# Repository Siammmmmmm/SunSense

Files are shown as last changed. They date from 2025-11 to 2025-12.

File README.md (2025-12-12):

# SunSense
>Automated Smart Blinds System

A real-time embedded system that automatically opens or closes window blinds based on ambient light level and user gestures. The system uses light sensors to detect brightness conditions and Time-of-Flight sensors with TinyML to recognize simple hand gestures for manual override.

# Setup and Deployment

To build this project, you'll need an Arduino Nano 33 BLE Sense Rev2, a Nema 17 stepper motor with DRV8825 driver, one TSL2561 light sensor, four VL53L1X Time of Flight sensors, and a 12V 3A power supply. Install the required Arduino libraries (Adafruit TSL2561, Adafruit VL53L1X, and Adafruit Unified Sensor) through the Arduino IDE Library Manager. Wire the TSL2561 to the Arduino's I2C pins (SDA/SCL) and 3.3V power. Connect all four VL53L1X sensors to the same I2C bus with their XSHUT pins connected to digital pins 5, 6, 7, and 8 to assign unique addresses during initialization. Wire the DRV8825 motor driver to the 12V power supply and connect its control pins: STEP to pin 2, DIR to pin 3, ENABLE to pin 4, and SLP (sleep) to pin 9. Connect the stepper motor to the driver's output pins. Clone the code and upload Main/SunSense.ino to your Arduino. The system uses three concurrent threads - one for light sensing, one for ToF data collection, and one for TinyML gesture recognition. Attach the motor to your blind rod using the 3D printed coupling that allows it to rotate the rod.

# How to Use and Interact

Once powered on, the system runs three parallel tasks automatically. The light sensing thread checks the ambient light level every 10 minutes and rotates the motor 3 full rotations to open or close the blinds when the light crosses the threshold of 6 lux. The ToF thread continuously samples all four distance sensors at approximately 20 Hz, and the Ai thread collects one second of ToF data and runs a TinyML gesture recognition model on it. When a gesture is detected with at least 95% confidence, the system overrides the automatic mode and toggles the blinds (with a 2-second cooldown between gestures to prevent accidental triggers). You can manually control the blinds by waving your hand toward the four ToF sensors positioned in front of the device. The system alternates between opening and closing with each detected gesture. All activity is logged to the Serial Monitor at 115200 baud if you want to debug or monitor the system's behavior.

>[Demo Link](https://buffalo.box.com/s/utygu3p5m2xhpubo7brv89h74q1jszoa)

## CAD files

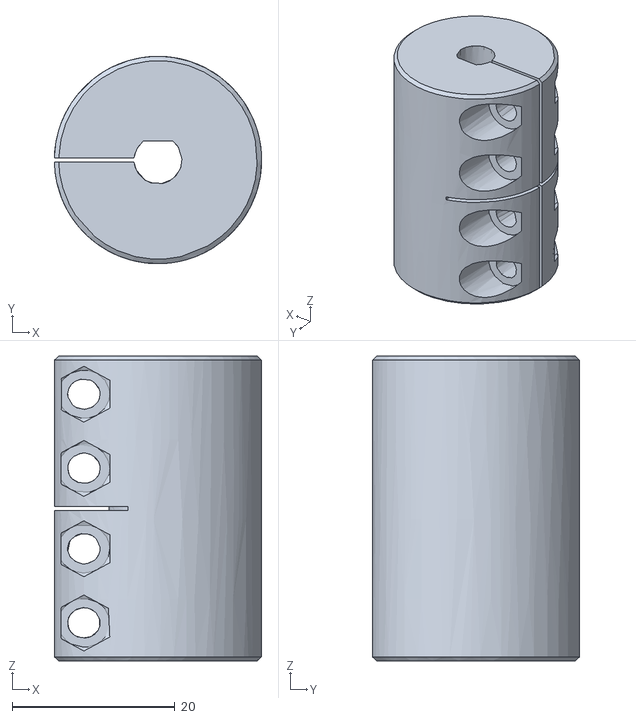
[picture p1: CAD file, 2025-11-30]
3DPrint/Coupler.stl
25.5 x 25.5 x 37.5

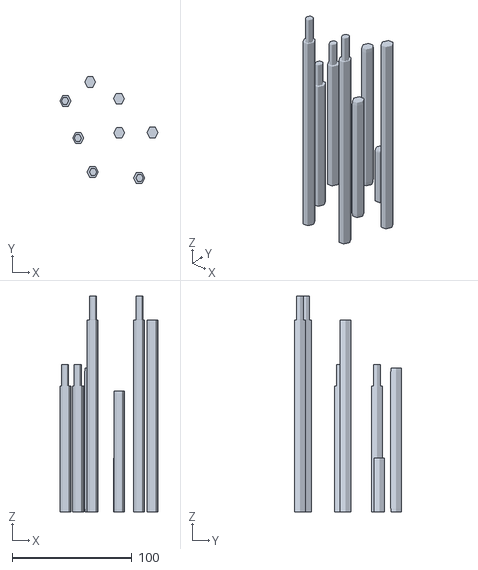
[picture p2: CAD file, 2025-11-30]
3DPrint/Rods.stl
81.8 x 89.2 x 180.0

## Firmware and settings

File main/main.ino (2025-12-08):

#include <Arduino.h>
#include <SunSense_inferencing.h>
#include "mbed.h"
#include <rtos.h>
#include <Wire.h>
#include <Adafruit_Sensor.h>
#include <Adafruit_TSL2561_U.h>
#include <VL53L1X.h>

using namespace mbed;
using namespace rtos;
using namespace std::chrono_literals;

// --- Pin Definitions ---
#define STEP_PIN 2
#define DIR_PIN 3
#define ENABLE_PIN 4  // DRV8825: LOW=enable, HIGH=disable
#define SLP_PIN 9     // LOW=disable, HIGH=enable

// --- tof ---
const uint8_t sensorCount = 4;

// Shared latest TOF readings (updated by tofThread, read by aiThread)
volatile uint16_t tofValues[sensorCount] = { 0, 0, 0, 0 };

// XSHUT pins
const uint8_t xshutPins[sensorCount] = { 5, 6, 7, 8 };

// --- motor out ---
DigitalOut stepPin(digitalPinToPinName(STEP_PIN));
DigitalOut dirPin(digitalPinToPinName(DIR_PIN));
DigitalOut enPin(digitalPinToPinName(ENABLE_PIN));
DigitalOut slpPin(digitalPinToPinName(SLP_PIN));

// --- Sensor Objects ---
Adafruit_TSL2561_Unified tsl = Adafruit_TSL2561_Unified(TSL2561_ADDR_FLOAT, 12345);
VL53L1X tof[sensorCount];

// --- Parameters ---
const int lightThreshold = 6;  // lux value to trigger movement (adjust as needed)
int bright = 1;
volatile bool motorActive = false;
// bool luxPause = false;

// --- RTOS objects ---
Mutex printMutex;  // guard Serial printing
Mutex motorMutex;  // guard motor operations
Mutex tofMutex;    // guard tof readings

Thread luxThread;
Thread tofThread;
Thread aiThread;

void pulse(int microsec) {
  stepPin = 1;
  wait_us(microsec);
  stepPin = 0;
  wait_us(microsec);
}

// motor moves
/*ex:
2 full rotations  = 2072 steps
full rotation     = 1036 steps
half              = 518 steps
quarter           = 259 steps
*/
void moveSteps(int steps, bool dir, int freqHz) {
  motorMutex.lock();
  motorActive = true;

  // Wake motor driver
  slpPin = 1;  // awake
  dirPin = dir ? 1 : 0;
  enPin = 0;  // enable driver

  {
    printMutex.lock();
    Serial.print("MOTOR : ");
    Serial.println(dir ? "Forward" : "Backward");
    printMutex.unlock();
  }

  int microsec = (int)(1e6 / (freqHz * 2.0f));
  for (long i = 0; i < steps; i++) pulse(microsec);

  enPin = 1;   // disable outputs (no idle heat)
  slpPin = 0;  // sleep

  motorActive = false;
  motorMutex.unlock();
}

void tofInit() {
  for (int i = 0; i < sensorCount; i++) {
    pinMode(xshutPins[i], OUTPUT);
    digitalWrite(xshutPins[i], LOW);
  }
  ThisThread::sleep_for(10ms);

  for (int i = 0; i < sensorCount; i++) {
    pinMode(xshutPins[i], INPUT);  //toggles xshut pins to later set proper address to indentify
    ThisThread::sleep_for(10ms);

    if (!tof[i].init()) {
      printMutex.lock();
      Serial.print("Failed to detect and initialize sensor ");
      Serial.println(i);
      printMutex.unlock();
      continue;
    }

    tof[i].setTimeout(50);
    tof[i].setDistanceMode(VL53L1X::Long);
    tof[i].setMeasurementTimingBudget(20000);  // 20ms == 20hz
    tof[i].setAddress(0x2A + i);
    tof[i].startContinuous(50);  // 1/50ms between readings == 20hz
  }
}

void luxInit() {
  if (!tsl.begin()) {
    printMutex.lock();
    Serial.println("SYSTEM: No TSL2561 found!");
    printMutex.unlock();
    return;
  }
  printMutex.lock();
  Serial.println("SYSTEM: TSL2561 initialized!");
  printMutex.unlock();

  tsl.enableAutoRange(true);
  tsl.setIntegrationTime(TSL2561_INTEGRATIONTIME_13MS);
}

void luxTask() {
  const int reps = 3;
  while (true) {
    sensors_event_t event;
    tsl.getEvent(&event);
    // if (luxPause) {
    //   ThisThread::sleep_for(10000ms);
    //   luxPause = false;
    //   continue;
    // }

    if (event.light && !isnan(event.light)) {
      printMutex.lock();
      Serial.print("LIGHT : ");
      Serial.print(event.light);
      Serial.println(" lux!");
      printMutex.unlock();

      if (event.light < lightThreshold && bright == 0) {
        printMutex.lock();
        Serial.println("LIGHT : Too dark -> rotating clockwise");
        printMutex.unlock();

        moveSteps(1036 * reps, true, 100);  // 1036 steps(1 full rotation * num of rotations), direction, motor hz
        bright = 1;                         // confirmation for blinds
      } else if (event.light > lightThreshold && bright == 1) {
        printMutex.lock();
        Serial.println("LIGHT : bright enough -> rotating counterclockwise");
        printMutex.unlock();

        moveSteps(1036 * reps, false, 100);  //1036 steps(1 full rotation * num of rotations), direction, motor hz
        bright = 0;
      }
    } else {
      printMutex.lock();
      Serial.println("LIGHT : No light data");
      printMutex.unlock();
    }

    ThisThread::sleep_for(600000ms);
  }
}

void tofTask() {
  const uint32_t SAMPLE_INTERVAL_MS = 50;  // 20hz

  while (true) {
    if (motorActive) {
      ThisThread::sleep_for(5ms);
      continue;
    }

    uint16_t local[4] = { 0, 0, 0, 0 };

    for (uint8_t i = 0; i < sensorCount; i++) {
      int d = tof[i].read();
      bool timedOut = tof[i].timeoutOccurred();

      // if bad, reuse last known good reading
      if (timedOut || d <= 0) {
        d = tofValues[i];  // previous stable value
      }

      // clamp to sane physical range, synthetic tof values
      if (d < 100) d = 100;    // 10m min
      if (d > 4000) d = 4000;  // 4m max
      // -=-=-Sensor failsafe (misbehaves)-=-=-

      local[i] = (uint16_t)d;
    }

    tofMutex.lock();
    for (uint8_t i = 0; i < sensorCount; i++) {
      tofValues[i] = local[i];
    }
    tofMutex.unlock();

    printMutex.lock();
    Serial.print("TOF: ");
    for (uint8_t i = 0; i < sensorCount; i++) {
      Serial.print(local[i]);
      if (i < sensorCount - 1) Serial.print(", ");
    }
    Serial.println();
    printMutex.unlock();

    ThisThread::sleep_for(SAMPLE_INTERVAL_MS * 1ms);
  }
}

void aiTask() {
  ei_impulse_result_t result = { 0 };

  // expects EI_CLASSIFIER_DSP_INPUT_FRAME_SIZE floats
  static float inference_buffer[EI_CLASSIFIER_DSP_INPUT_FRAME_SIZE];  //Frame stuff given by EI: idk how this exactly works lol
  size_t buf_idx = 0;

  const uint32_t SAMPLE_INTERVAL_MS = 50;  // match TOF sampling at 50ms or 20hz
  const float GESTURE_THRESHOLD = 0.95f;   // 95% confidence needed
  uint32_t last_action_time = 0;
  const uint32_t COOLDOWN_MS = 2000;  // 2s cooldown between actions

  // extra gating
  const float MARGIN_THRESHOLD = 0.25f;  // gesture must beat next class by 0.25
  const int MOTION_THRESHOLD_MM = 50;    // min movement in mm to count as "motion"
  static int consecutive_gesture = 0;

  static bool first_sample = true;
  static uint16_t prev_tof[4] = { 0, 0, 0, 0 };
  static bool window_has_motion = false;

  // Find index of "gesture" label
  int gesture_idx = -1;
  for (size_t i = 0; i < EI_CLASSIFIER_LABEL_COUNT; i++) {
    if (strcmp(ei_classifier_inferencing_categories[i], "gesture") == 0) {
      gesture_idx = (int)i;
      break;
    }
  }
  if (gesture_idx < 0) {
    printMutex.lock();
    Serial.println("ERROR: 'gesture' label not found in model!");
    printMutex.unlock();
    return;
  }

  while (true) {
    // 1. Read latest TOF values under mutex
    uint16_t current_tof[4];
    tofMutex.lock();
    for (uint8_t i = 0; i < sensorCount; i++) {
      current_tof[i] = tofValues[i];
    }
    tofMutex.unlock();

    // --- motion detection vs previous sample ---
    if (first_sample) {
      for (int i = 0; i < 4; i++) prev_tof[i] = current_tof[i];
      first_sample = false;
    }

    int max_delta = 0;  //start to track changes in motion
    for (int i = 0; i < 4; i++) {
      int diff = (int)current_tof[i] - (int)prev_tof[i];
      if (diff < 0) diff = -diff;
      if (diff > max_delta) max_delta = diff; //checks if more than 50mm changed (redundant stuff to not over work the aithread)
    }
    for (int i = 0; i < 4; i++) prev_tof[i] = current_tof[i];

    if (max_delta > MOTION_THRESHOLD_MM) {
      window_has_motion = true;
    }

    // 2. Push one "frame" (4 sensors) into inference buffer
    inference_buffer[buf_idx++] = (float)current_tof[0];
    inference_buffer[buf_idx++] = (float)current_tof[1];
    inference_buffer[buf_idx++] = (float)current_tof[2];
    inference_buffer[buf_idx++] = (float)current_tof[3];

    // 3. When buffer full then 1 second of data collected
    if (buf_idx >= EI_CLASSIFIER_DSP_INPUT_FRAME_SIZE) {
      signal_t signal;

      int sf_res = numpy::signal_from_buffer(
        inference_buffer,
        EI_CLASSIFIER_DSP_INPUT_FRAME_SIZE,
        &signal);

      if (sf_res != 0) {
        printMutex.lock();
        Serial.print("signal_from_buffer failed: ");
        Serial.println(sf_res);
        printMutex.unlock();
      } else {
        EI_IMPULSE_ERROR rc = run_classifier(&signal, &result, false);

        if (rc != EI_IMPULSE_OK) {
          printMutex.lock();
          Serial.print("run_classifier failed: ");
          Serial.println((int)rc);
          printMutex.unlock();
        } else {

          if (!window_has_motion) {
            // no motion in this window so ignore any "gesture" output
            printMutex.lock();
            Serial.println("ML: window had no motion, forcing no_gesture");
            printMutex.unlock();
            consecutive_gesture = 0;
          } else {
            // 4. Find top-2 labels
            float gesture_prob = result.classification[gesture_idx].value;

            int best_idx = 0;
            float best_prob = result.classification[0].value;
            int second_idx = -1;
            float second_prob = 0.0f;

            // collects multiple frames into a window and chooses the best stable one and feeds into classifier
            for (size_t i = 1; i < EI_CLASSIFIER_LABEL_COUNT; i++) {
              float p = result.classification[i].value;
              if (p > best_prob) { 
                second_prob = best_prob;
                second_idx = best_idx;
                best_prob = p;
                best_idx = (int)i;
              } else if (p > second_prob) {
                second_prob = p;
                second_idx = (int)i;
              }
            }

            float margin = best_prob - second_prob;

            // Debug all labels
            printMutex.lock();
            Serial.println("===== CLASSIFIER OUTPUT =====");
            for (size_t i = 0; i < EI_CLASSIFIER_LABEL_COUNT; i++) {
              Serial.print("  ");
              Serial.print(ei_classifier_inferencing_categories[i]);
              Serial.print(": ");
              Serial.println(result.classification[i].value, 3);
            }
            printMutex.unlock();

            // 5. Decide if gesture is real
            const float MARGIN_THRESHOLD = 0.15f;  // difference between best & 2nd-best

            bool gesture_detected =
              (best_idx == gesture_idx) && (best_prob >= GESTURE_THRESHOLD) && (margin >= MARGIN_THRESHOLD);

            uint32_t now = millis();

            if (gesture_detected && (now - last_action_time) >= COOLDOWN_MS) { //stops from multiple instances of gesture detection

              printMutex.lock();
              Serial.println(">>> GESTURE DETECTED (single window), MOVING MOTOR");
              printMutex.unlock();

              // luxPause = true; //stops the lux sensor for a while after gesture override

              motorMutex.lock();
              if (bright == 0) {
                moveSteps(3 * 1036, true, 100);
                bright = 1; //sets the blinds to open
              } else {
                moveSteps(3 * 1036, false, 100);
                bright = 0;
              }
              motorMutex.unlock();

              last_action_time = now;  // reset cooldown
            }
          }  // end window_has_motion check
        }
      }

      // reset for next 1-second window
      window_has_motion = false;
      buf_idx = 0;
    }

    ThisThread::sleep_for(SAMPLE_INTERVAL_MS * 1ms);
  }
}

void setup() {
  Serial.begin(115200);
  ThisThread::sleep_for(500ms);
  Wire.begin();
  Wire.setClock(400000);

  printMutex.lock();
  Serial.println("~--===STARTING SunSense===--~");
  printMutex.unlock();

  // --- Initialize motor driver pins ---
  enPin = 1;   // start disabled
  slpPin = 0;  // enable later
  stepPin = 0;
  dirPin = 0;
  ThisThread::sleep_for(100ms);

  luxInit();  //lux sensor
  ThisThread::sleep_for(50ms);
  tofInit();  //tof sensor
  ThisThread::sleep_for(50ms);

  printMutex.lock();
  Serial.println("SYSTEM: All sensors ready!");
  printMutex.unlock();

  // Start threads
  tofThread.start(tofTask);
  aiThread.start(aiTask);
  luxThread.start(luxTask);
}

void loop() {
}

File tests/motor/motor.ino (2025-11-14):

#include <Arduino.h>
#include "mbed.h"

#define STEP_PIN 2
#define DIR_PIN  3
#define EN_PIN   4   // DRV8825: LOW=enable, HIGH=disable
#define SLP_PIN  9  // LOW=disable, HIGH=enable

using namespace mbed;
DigitalOut stepPin(digitalPinToPinName(STEP_PIN));
DigitalOut dirPin (digitalPinToPinName(DIR_PIN));
DigitalOut enPin  (digitalPinToPinName(EN_PIN));
DigitalOut slpPin (digitalPinToPinName(SLP_PIN));


void pulseOnce(int microsec){
  stepPin = 1; wait_us(microsec);
  stepPin = 0; wait_us(microsec);
}

// simple move with enable only during motion
void moveSteps(long steps, bool dir, int freqHz){
  slpPin = 1; // awake
  Serial.println(dir ? "Forward" : "Backward"); //true = clockwise : false = counterclockwise
  dirPin = dir ? 1 : 0;
  enPin  = 0;                 // enable driver
  int microsec = (int)(1e6/(freqHz*2.0));
  for(long i=0;i<steps;i++) pulseOnce(microsec);
  enPin  = 1;                 // disable outputs (no idle heat)
  slpPin = 0; //sleep
}

void setup(){
  Serial.begin(115200);
  
  enPin = 1;                  // start disabled
  slpPin = 1;
  stepPin = 0;
  dirPin = 0;
  moveSteps(1036, true, 80); 
  delay(1500);
  moveSteps(1036, false, 80);
}

void loop(){
  // Example: ~1/4 turn (≈259 steps on 5.18:1)
    // start slow (50–100 Hz)
                // plenty of idle time with coils off
}

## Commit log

2025-11-04 Code for motor
2025-11-04 Added sensor testing
2025-11-05 changed the delaymicro to wait commented out other sensors
2025-11-05 added driver voltage check
2025-11-07 motor set up
2025-11-11 added motor function to main
2025-11-14 Disabled sleep in motor tests to reduce idle heat
2025-11-14 standardized debug print lines
2025-11-30 added the 3d printed parts and some tests
    [Coupler.stl, Rods.stl]
2025-12-02 using new tof sensor library
2025-12-08 fixed sleep pin bug and added more comments
    [main.ino]
